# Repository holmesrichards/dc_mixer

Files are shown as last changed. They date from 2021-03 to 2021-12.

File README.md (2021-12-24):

## AO DC Mixer

This is a DC coupled 3-input mixer, designed mainly for mixing control voltage signals. It is based loosely on the MFOS Quad DC mixer (but only one unit per module). A lot has been changed:

* For a general gain control, split MFOS's first op amp stage into an inverting variable gain mixing stage and an inverting unity gain with bias stage. This means MFOS's normal output became the inverted output and vice versa.
* In Wilson's design, bias was applied to stage with 3 summed inputs so output was -(V<sub>1</sub>+V<sub>2</sub>+V<sub>3</sub>)+4V<sub>bias</sub>, so he needed 4V<sub>bias</sub> going into the last stage to get output of (V<sub>1</sub>+V<sub>2</sub>+V<sub>3</sub>)+4V<sub>bias</sub>. Hence the gain of 4 on the bias amplification stage. Here the sum is separated from the bias, so bias stage output is -(V<sub>1</sub>+V<sub>2</sub>+V<sub>3</sub>)+2V<sub>bias</sub>. Therefore changed gain from 4 to 2. Also, to get same offset range, changed the offset voltage divider to divide by 2, not 4.
* Added antiparallel diodes and a pulldown resistor in the offset voltage divider, a la YuSynth mixer. This and the small value resistors makes the response to the offset knob knob S shaped, with a flat region around 0 V, reaching about ±10.2 V offset at extreme ends. 
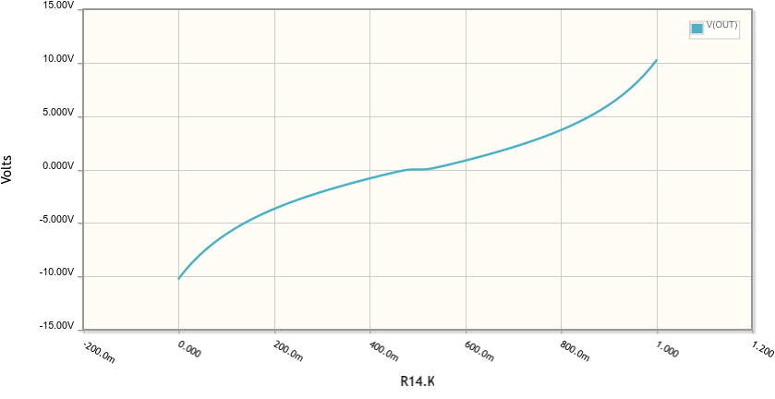
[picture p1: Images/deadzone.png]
Bias dead zone
 
Note, if rails are asymmetric it shifts the inflection point horizontally but *not* vertically, which is great! -12 V and +11 V by simulation gives an S centered at about 48% pot position and 0 V.
* Reduced impedances in most stages.

## Current draw
9 mA +12 V, 9 mA -12 V

## Documentation

* [Build notes and calibration](Docs/build_notes.md) 
* [Schematic](Docs/ao_dc_mixer.pdf)
* [BOM](Docs/ao_dc_mixer_bom.pdf)

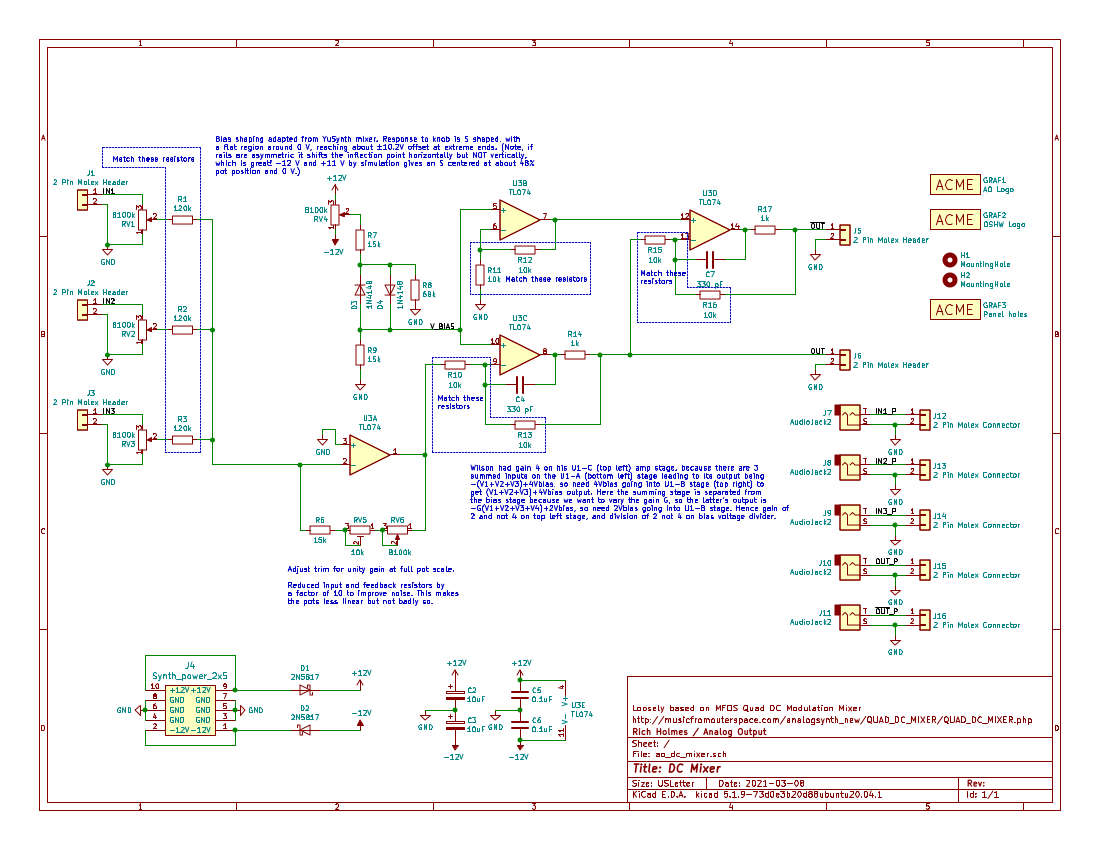
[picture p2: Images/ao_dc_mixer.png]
 
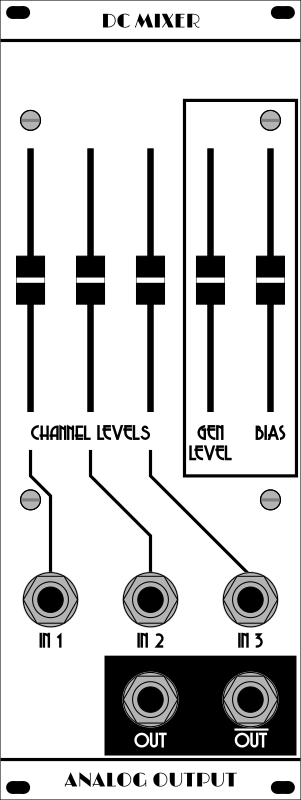
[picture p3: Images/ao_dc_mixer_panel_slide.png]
 

Repo uses submodules aoKicad and Kosmo_panel. To clone:

```
git clone git@github.com:holmesrichards/dc_mixer.git
git submodule init
git submodule update
```

Alternatively do

```
git clone --recurse-submodules git@github.com:holmesrichards/dc_mixer.git
```

Or if you download the repository as a zip file, you must also click on the "aoKicad" and "Kosmo\_panel" links on the GitHub page (they'll have "@ something" after them) and download them as separate zip files which you can unzip into this repo's aoKicad and Kosmo\_panel directories.

If desired, copy the files from aoKicad and Kosmo\_panel to wherever you prefer (your KiCad user library directory, for instance, if you have one). Then in KiCad, add symbol libraries 

```
aoKicad/ao_symbols
Kosmo_panel/Kosmo
```
and footprint libraries 
```
aoKicad/ao_tht
Kosmo_panel/Kosmo_panel.
```

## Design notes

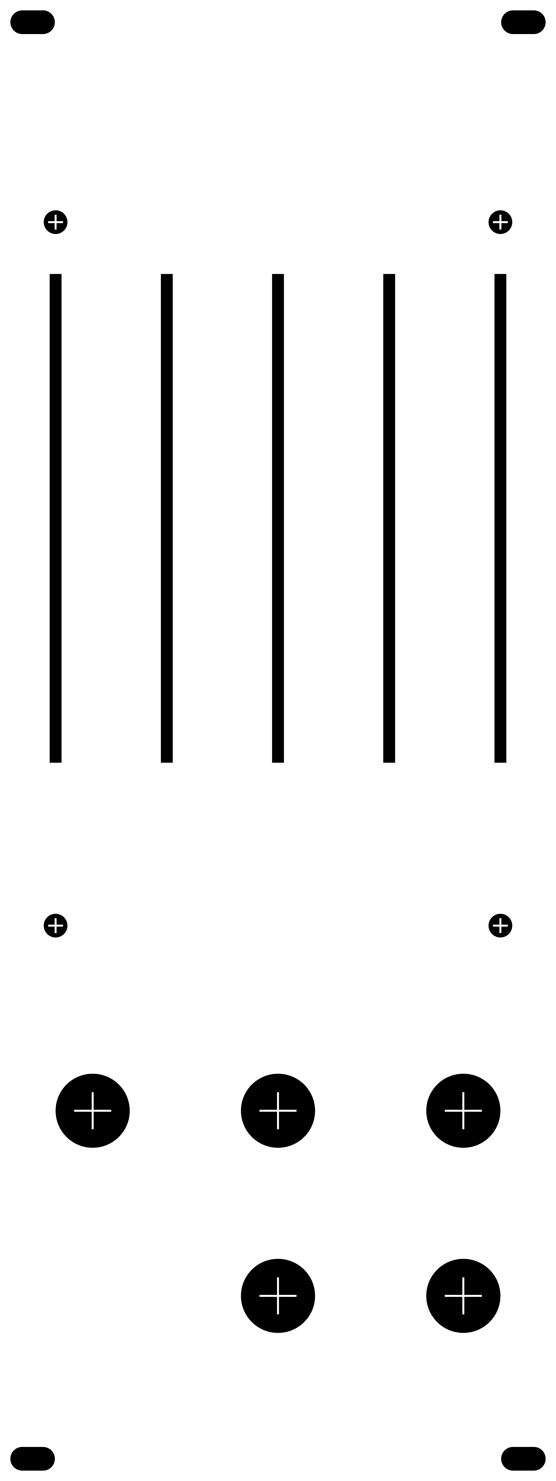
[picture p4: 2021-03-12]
Images/ao_dc_mixer_panel_slide_holes.png

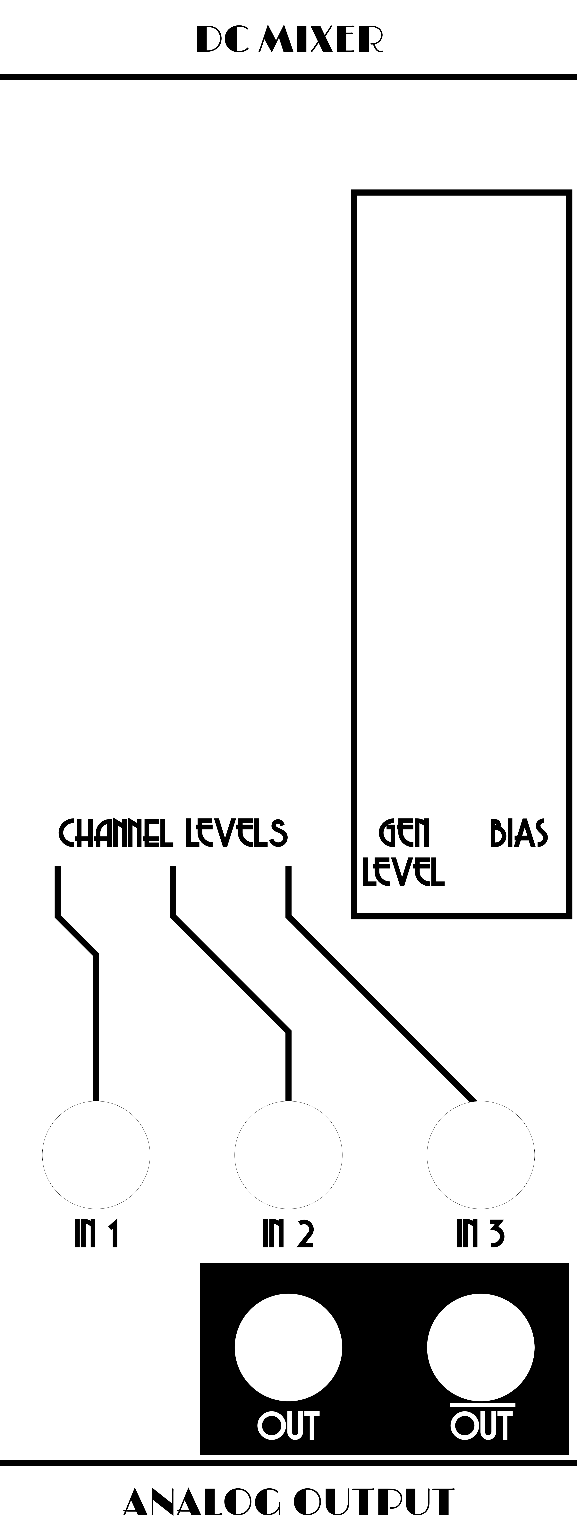
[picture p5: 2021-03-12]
Images/ao_dc_mixer_panel_slide_art.png

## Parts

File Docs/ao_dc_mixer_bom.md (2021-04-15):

# Analog Output DC Mixer BOM

Thu 01 Apr 2021 02:14:44 PM EDT

Generated from schematic by Eeschema 5.1.9-73d0e3b20d~88~ubuntu20.04.1

**Component Count:** 48

| Refs | Qty | Component | Description | Manufacturer | Part | Vendor | SKU |
| ----- | --- | ---- | --- | ---- | ---- | ---- | ---- |
| C2, C3 | 2 | 10uF | Electrolytic capacitor |  |  |  |  |
| C4, C7 | 2 | 330 pF | Ceramic capacitor |  |  |  |  |
| C5, C6 | 2 | 0.1uF | Ceramic capacitor |  |  |  |  |
| D1, D2 | 2 | 2N5817 | Schottky diode |  |  |  |  |
| D3, D4 | 2 | 1N4148 | 100V 0.15A standard switching diode, DO-35 |  |  |  |  |
| J1, J2, J3, J5, J6 | 5 | 2 Pin Molex Header | 2 pin Molex header 2.54 mm spacing |  |  | Tayda | A-804 |
| J4 | 1 | Synth_power_2x5 | 2x5 pin shrouded header 2.54 mm spacing |  |  | Tayda | A-2939 |
| J7, J8, J9, J10, J11 | 5 | AudioJack2 | Audio Jack, 2 Poles (Mono / TS) |  |  |  |  |
| J12, J13, J14, J15, J16 | 5 | 2 Pin Molex Connector | 2 pin Molex connector 2.54 mm spacing |  |  | Tayda | A-826 |
| R1, R2, R3 | 3 | 120k | Resistor (matched) |  |  |  |  |
| R6, R7, R9 | 3 | 15k | Resistor |  |  |  |  |
| R8 | 1 | 68k | Resistor |  |  |  |  |
| R10, R11, R12, R13, R15, R16 | 6 | 10k | Resistor (matched in pairs) |  |  |  |  |
| R14, R17 | 2 | 1k | Resistor |  |  |  |  |
| RV1, RV2, RV3, RV4, RV6 | 5 | B100k | Slide potentiometer | Alpha | RA6020F | Tayda | A-4496 |
| RV5 | 1 | 10k | Trim-potentiometer | Alpha | 3296W | Tayda | A-586 |
| U3 | 1 | TL074 | Quad Low-Noise JFET-Input Operational Amplifiers, DIP-14 |  |  |  |  |
| | 1 | | 14 pin DIP socket | | | | |
| | 5 | | Knobs | | | | |
| | 2 | | M3 10 mm screws | | | | |
| | 2 | | M3 6 mm screws | | | | |
| | 2 | | M3 5 mm female-female spacers | | | | |
| | 2 | | M3 20 mm male-female spacers | | | | |
| | 2 | | M3 nuts | | | | |
    
C1, U1, U2 references not used

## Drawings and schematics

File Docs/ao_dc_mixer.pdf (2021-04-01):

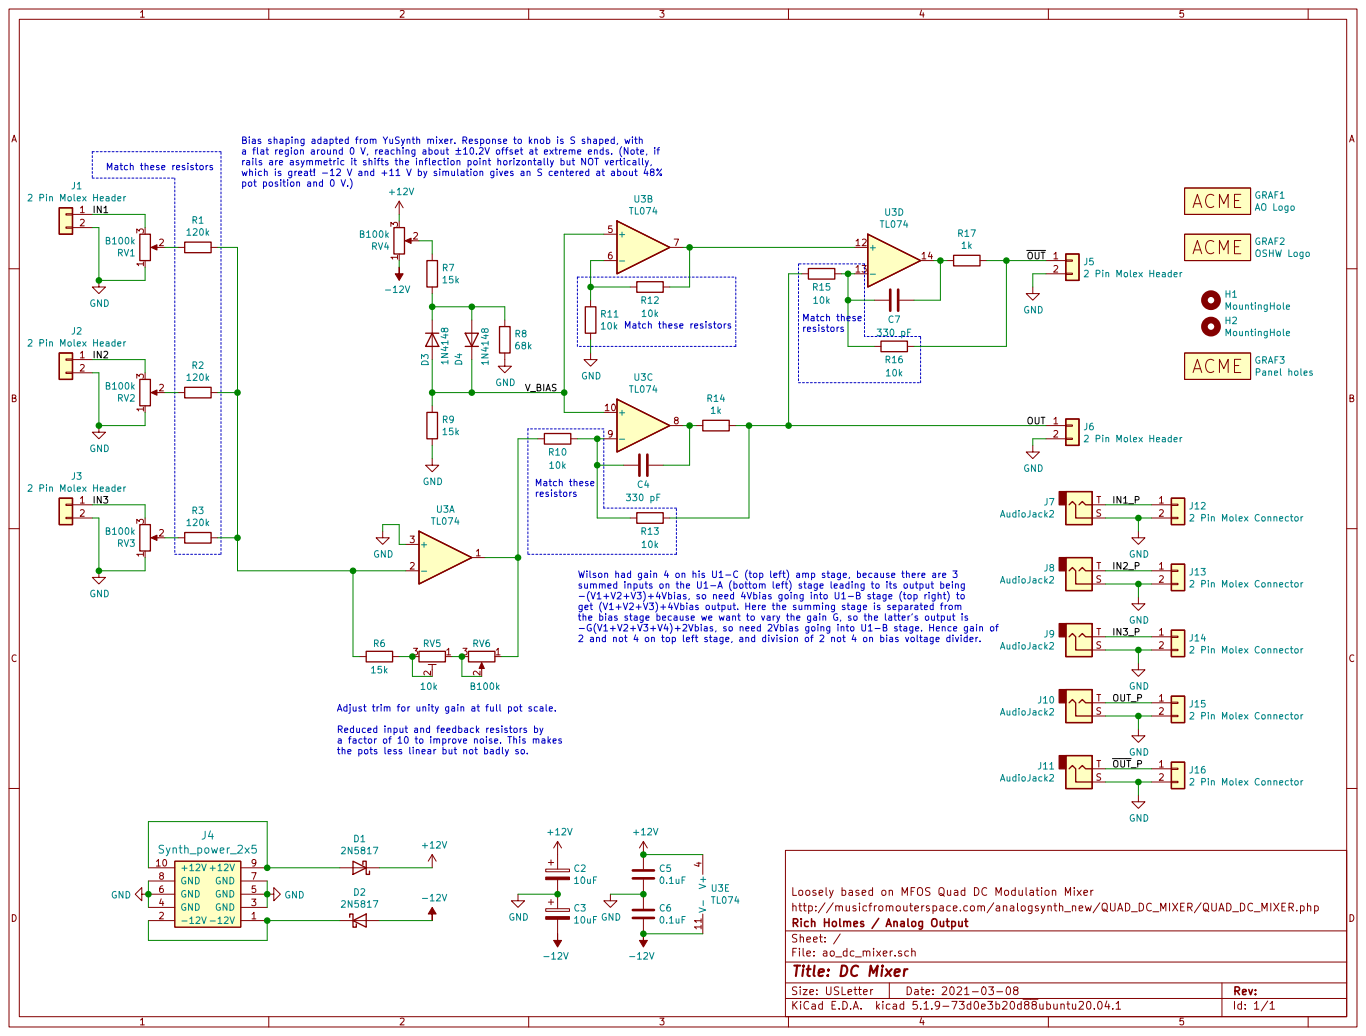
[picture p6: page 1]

a flat region around 0 V, reaching about ±10.2V offset at extreme ends. (Note, if
rails are asymmetric it shifts the inflection point horizontally but NOT vertically,
which is great! -12 V and +11 V by simulation gives an S centered at about 48%

summed inputs on the U1-A (bottom left) stage leading to its output being
-(V1+V2+V3)+4Vbias, so need 4Vbias going into U1-B stage (top right) to
get (V1+V2+V3)+4Vbias output. Here the summing stage is separated from
the bias stage because we want to vary the gain G, so the latter's output is
-G(V1+V2+V3+V4)+2Vbias, so need 2Vbias going into U1-B stage. Hence gain of
2 and not 4 on top left stage, and division of 2 not 4 on bias voltage divider.

Reduced input and feedback resistors by
a factor of 10 to improve noise. This makes
the pots less linear but not badly so.

2 Pin Molex Connector GND

Loosely based on MFOS Quad DC Modulation Mixer
http://musicfromouterspace.com/analogsynth_new/QUAD_DC_MIXER/QUAD_DC_MIXER.php
File: ao_dc_mixer.sch Sheet: / Rich Holmes / Analog Output

Id: 1/1 Title: DC Mixer

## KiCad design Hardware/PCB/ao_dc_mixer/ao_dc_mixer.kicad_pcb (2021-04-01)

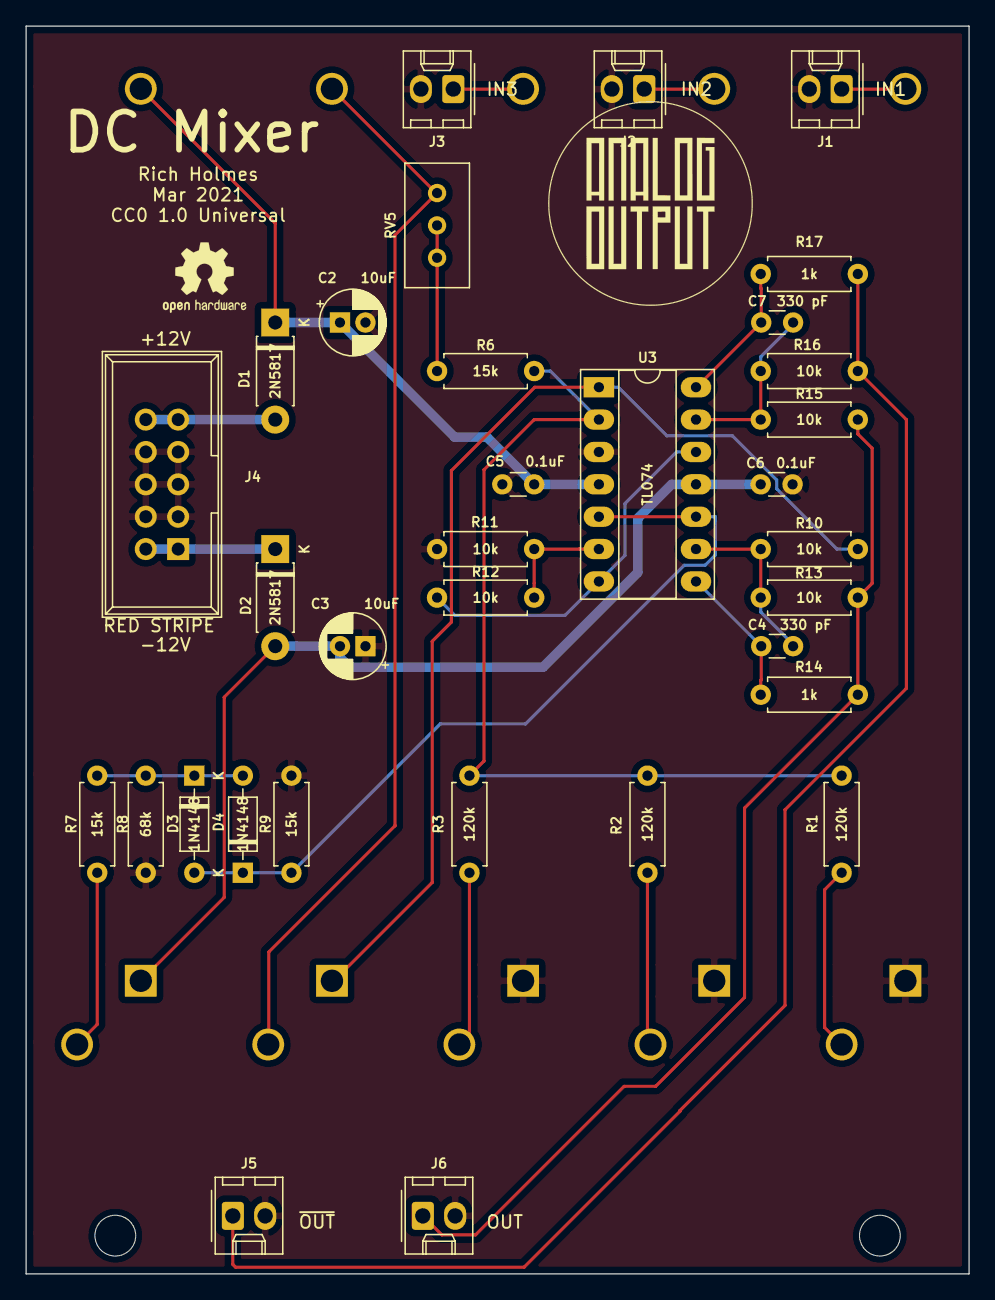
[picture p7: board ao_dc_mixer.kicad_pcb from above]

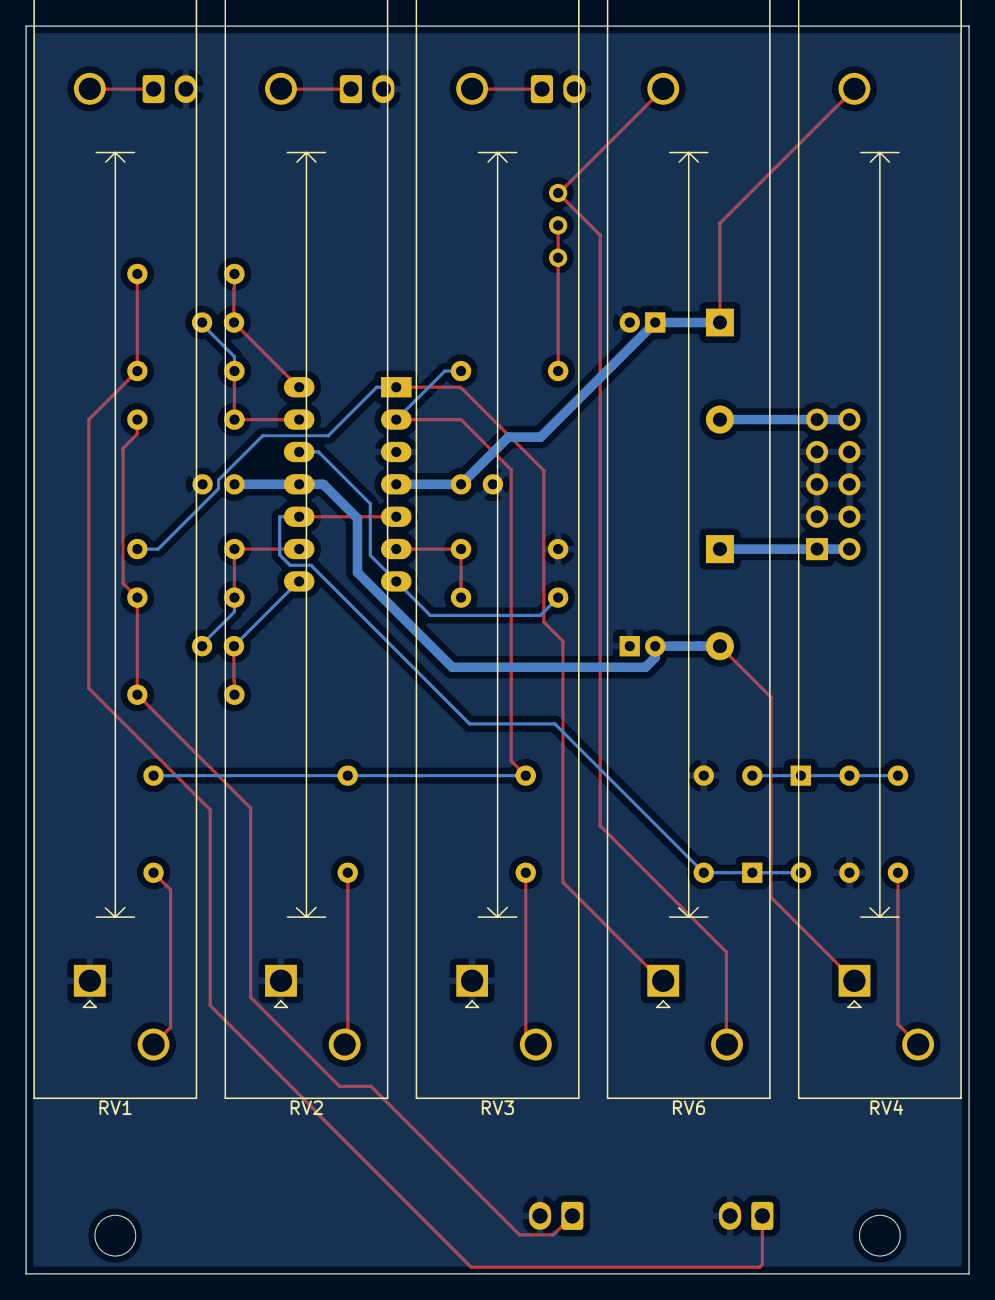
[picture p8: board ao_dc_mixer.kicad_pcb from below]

Board: 2 copper layers, 74.0 x 97.9 mm, 43 parts (5 on the bottom side), 26 nets.

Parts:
C2, C3: 10uF; CP_Radial_D5.0mm_P2.00mm
C4, C7: 330 pF; C_Disc_D3.0mm_W1.6mm_P2.50mm
C5, C6: 0.1uF; C_Disc_D3.0mm_W1.6mm_P2.50mm
D1, D2: 2N5817; D_DO-41_SOD81_P7.62mm_Horizontal
D3, D4: 1N4148; D_DO-35_SOD27_P7.62mm_Horizontal
GRAF1: AO Logo; analogoutput
GRAF2: OSHW Logo; OSHW-Logo2_7.3x6mm_SilkScreen
GRAF3: Panel holes; ao_dc_mixer_slide_holes
H1, H2: MountingHole; MountingHole_3.2mm_M3
J1, J2, J3, J5, J6: 2 Pin Molex Header; Molex_KK-254_AE-6410-02A_1x02_P2.54mm_Vertical
J4: Synth_power_2x5; Power_Header
R1, R2, R3: 120k; R_Axial_DIN0207_L6.3mm_D2.5mm_P7.62mm_Horizontal
R6, R7, R9: 15k; R_Axial_DIN0207_L6.3mm_D2.5mm_P7.62mm_Horizontal
R8: 68k; R_Axial_DIN0207_L6.3mm_D2.5mm_P7.62mm_Horizontal
R10, R11, R12, R13, R15, R16: 10k; R_Axial_DIN0207_L6.3mm_D2.5mm_P7.62mm_Horizontal
R14, R17: 1k; R_Axial_DIN0207_L6.3mm_D2.5mm_P7.62mm_Horizontal
RV1, RV2, RV3, RV4, RV6: B100k; Potentiometer_Alpha_RA6020F_Single_Slide
RV5: 10k; Potentiometer_Bourns_3296W_Vertical
U3: TL074; DIP-14_W7.62mm_Socket_LongPads

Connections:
+12V: C2.1, C5.1, D1.1, RV4.3, U3.4
-12V: C3.2, C6.2, D2.2, RV4.1, U3.11
/IN1: J1.1, RV1.3
/IN2: J2.1, RV2.3
/IN3: J3.1, RV3.3
/OUT: J6.1, R13.1, R14.1, R15.2
/V_BIAS: D3.2, D4.1, R9.1, U3.5, U3.10
/~OUT: J5.1, R16.1, R17.1
GND: C2.2, C3.1, C5.2, C6.1, J1.2, J2.2, J3.2, J4.3, J4.4, J4.5, J4.6, J4.7, J4.8, J5.2, J6.2, R8.2, R9.2, R11.2, RV1.1, RV2.1, RV3.1, U3.3
unnamed: C4.1, R10.1, R13.2, U3.9
unnamed: C4.2, R14.2, U3.8
unnamed: C7.1, R15.1, R16.2, U3.13
unnamed: C7.2, R17.2, U3.14
unnamed: D1.2, J4.9, J4.10
unnamed: D2.1, J4.1, J4.2
unnamed: D3.1, D4.2, R7.2, R8.1
unnamed: R1.1, R2.1, R3.1, R6.2, U3.2
unnamed: R1.2, RV1.2
unnamed: R2.2, RV2.2
unnamed: R3.2, RV3.2
unnamed: R6.1, RV5.2, RV5.3
unnamed: R7.1, RV4.2
unnamed: R10.2, RV6.1, U3.1
unnamed: R11.1, R12.2, U3.6
unnamed: R12.1, U3.7, U3.12
unnamed: RV5.1, RV6.2, RV6.3

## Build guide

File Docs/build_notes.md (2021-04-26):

# DC Mixer build notes and calibration

## Build notes

For reasonably accurate unity gain, take care to match all three input resistors (R1, R2, R3). They don't have to be accurately 120k but they should be equal to each other to within 0.1k. Also match the resistor pairs R11 and R12, R10 and R13, and R15 and R16. Again the exact values don't matter as long as the two resistors in each pair are equal, this time at the 0.01k level if possible.

The sum of R6, RV6 (at maximum), and RV5 is supposed to be 120k — or whatever your R1, R2, R3 are. Pots have loose tolerances, so check your slide pots before soldering them and make sure you use one for RV6 that isn't too small or too large! Choose one as close as possible to 100k, and definitely no less than 95k and no more than 105k. Or you can use a higher or lower value for R6 if needed to get R6 plus RV6 as close as possible to 115k. (I didn't check, and used a slide pot whose total resistance was too small; I had to unsolder R6 and replace it with a 22k.)

The slide pots are soldered to the back side of the PCB. Do check your assembly work on all the rest of the components before installing the slide pots! Once they are in place, any debugging work will either have to be done from the top side only, or will have to involve unsoldering slide pots. As usual with board mounted panel components, put them in place but don't solder, attach the front panel, then solder.

The screws in the top two panel mounting holes go into the left and right slide pots. You can attach the panel directly to the surface of the sliders but I find the shafts stick out too far. I used 5 mm spacers between the sliders and the panel; ideally these would be unthreaded, but I got away with threaded ones. Then I used 20 mm male-female spacers to secure the PCB at the bottom to the panel using the bottom two mounting holes. 

All Molex headers have the ground connection on the left when looking at them with the locking tab on top:

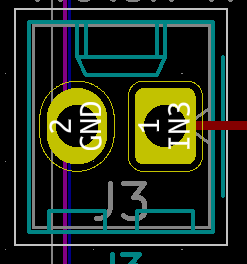
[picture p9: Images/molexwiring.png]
 

Of course you can solder the wires directly to the PCB if you don't want to use Molex connectors.

The ground wire goes to the sleeve pin on the jack and the other wire goes to tip:

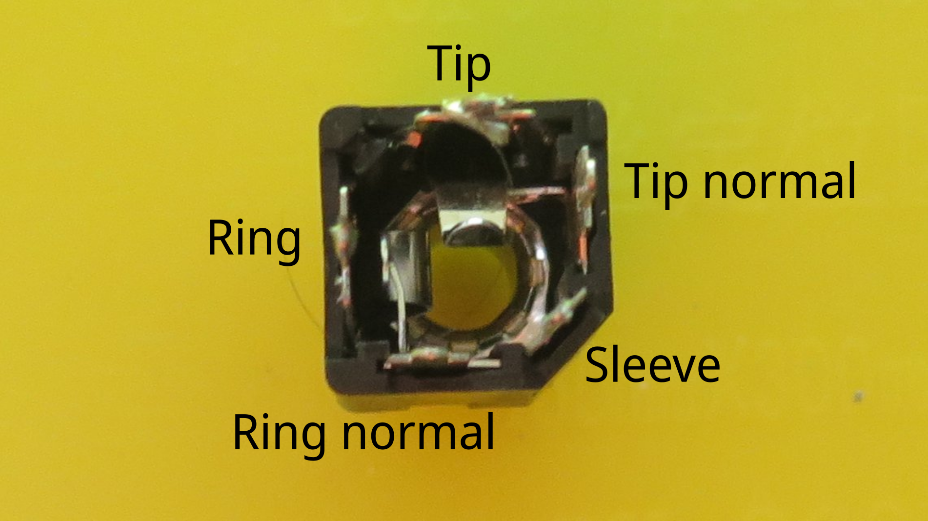
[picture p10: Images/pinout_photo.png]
 

## Calibration

To calibrate the mixer, set sliders RV1 and RV6 (Channel 1 Level and Gen Level) up to maximum. With no CV into Input 1, adjust the Bias slider to get the voltage from output to ground as close as possible to 0 V. Then put a CV of a few volts into Input 1 and connect your multimeter between the tip terminals of the Input 1 and Output jacks. Adjust trimmer RV5 until the voltage difference measured is 0 V. That should give you unity gain on the first input channel; you can verify that if you change the input CV, the voltage difference remains 0 V. You can check the other two channels similarly to verify they also are unity gain.

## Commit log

2021-03-08 initial version
    [ao_dc_mixer.kicad_pcb, ao_dc_mixer.sch]
2021-03-12 PCB and panel design
    [ao_dc_mixer-panel.kicad_pcb, ao_dc_mixer-panel.sch, ao_dc_mixer.kicad_pcb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]
2021-03-14 rm cap on first stage
2021-03-17 Various revisions, new DNF symbols
    [ao_dc_mixer.kicad_pcb, ao_dc_mixer.sch]
2021-04-01 Gerbers, BOM, final version before fabrication
    [ao_dc_mixer-B_Cu.gbr, ao_dc_mixer-B_Mask.gbr, ao_dc_mixer-B_Paste.gbr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]
2021-04-01 Update schematic PDF
2021-04-10 BOM updates
2021-12-24 Current draw
